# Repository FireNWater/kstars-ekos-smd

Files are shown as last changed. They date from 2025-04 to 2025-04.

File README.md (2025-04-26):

This is the Readme for my Raspberry Pi-5 Hat to control Astrophotography equipment.

This repository comes with absolutely NO Warranty, and is currently "in work".  There are several improvements I need to make to this design, the first of which is redesigning to use a larger format 5V buck converter.  The current buck converter is very small and difficult to solder using home shop air soldering techniques.

There is also a wiring bug in the 1-wire connections.  If you are going to use 1-wire, please connect directly to your Rpi or you will burn up your device and possibly the Rpi's power supply.

The UART connection works successfully.  Use ttyAMA0 and enable "UART0" on your Rpi.

I am planning on doing a complete rework of this design, hopefully before the end of 2025.  Planned improvements:

    1. Rework the Anderson Power Poles so they are used as stock instead of needing to be bent.
    2. Rework the APPs so they have a much more solid mount to the hat
    3. Extend the hat so it extends to the edge of the ethernet socket - more real estate
    4. I have found a larger 5V buck regulator that is much easier to solder using home hot air techniques
    5. Figure out why 1-wire circuit burns up the devices . . 
    6. There is a wiring bug that is fixed in the schematic, but is not fixed on the board traces.  This bug requires a bodge wire be installed on the 5V regulator to make it stable.  This is also very difficult to install.

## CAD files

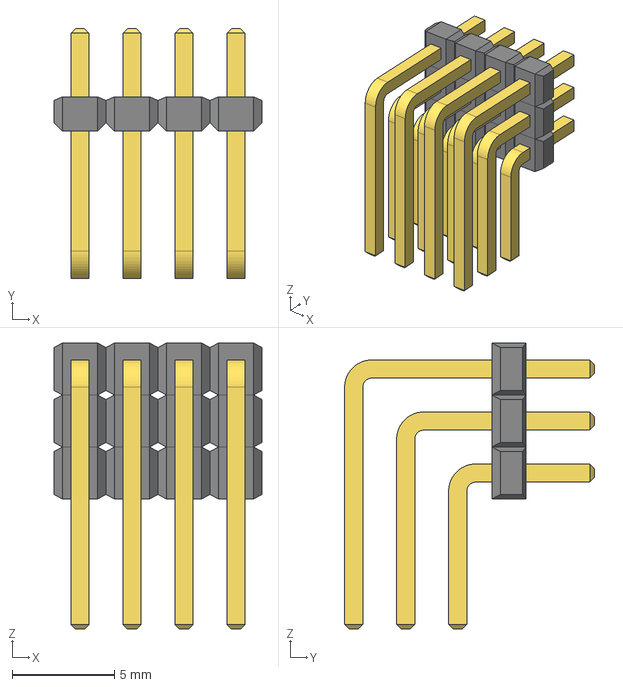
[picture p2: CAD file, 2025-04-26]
Project Library/TSW_104_08_G_T_RA/KiCADv6/TSW-104-08-T-T-RA_SAI.step
10.2 x 12.2 x 14.0 mm

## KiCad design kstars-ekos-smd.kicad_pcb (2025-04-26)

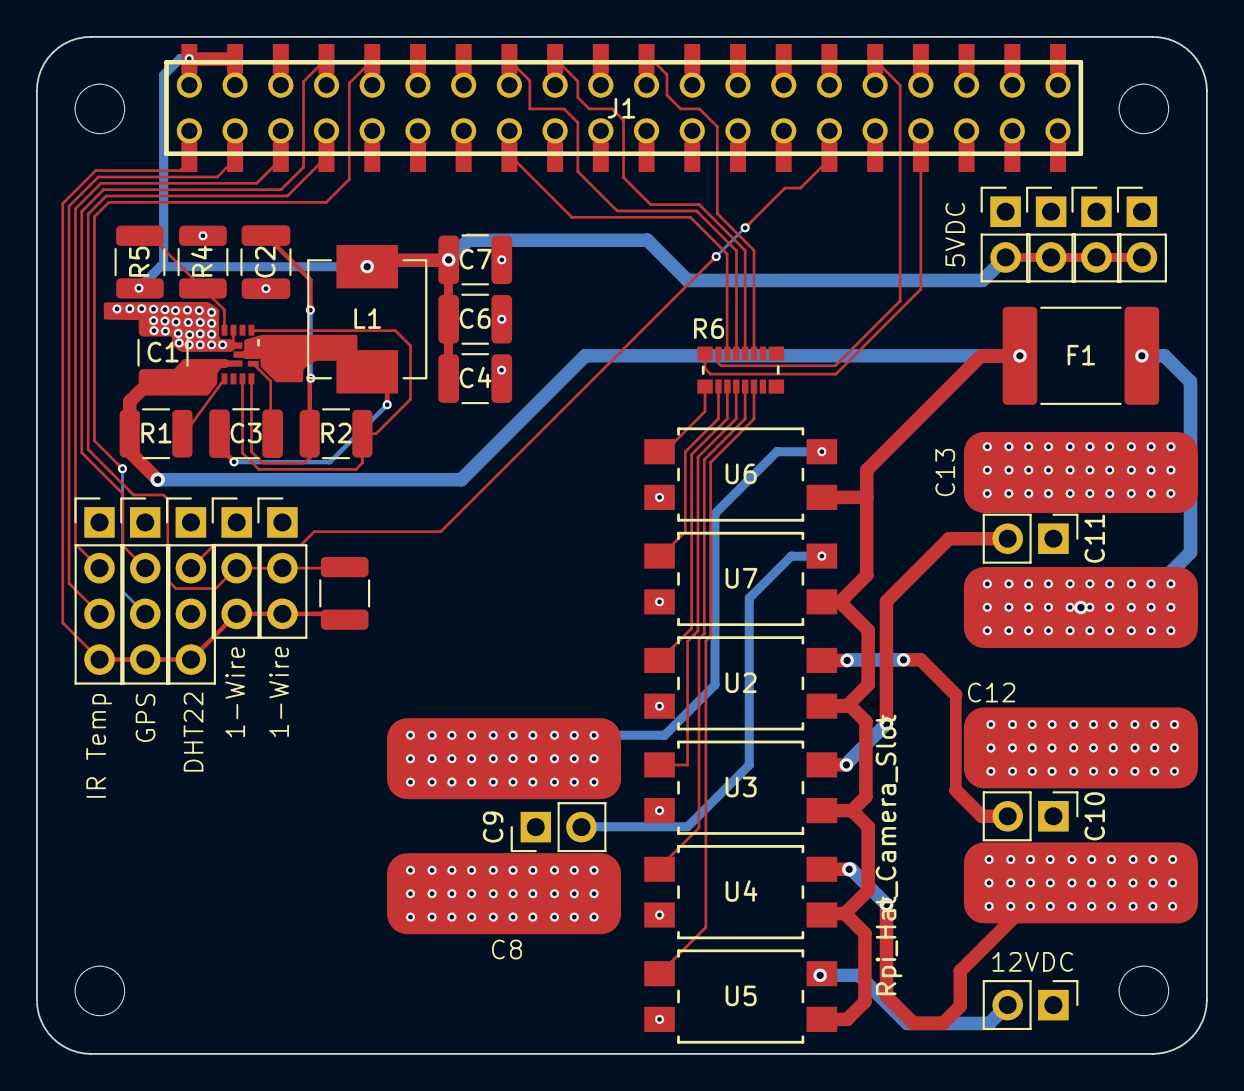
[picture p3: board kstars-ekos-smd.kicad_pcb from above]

Board: 2 copper layers, 65.0 x 56.5 mm, 38 parts (0 on the bottom side), 35 nets.

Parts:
C1, C4, C6, C7: 22uF; C_1210_3225Metric
C2: 1uF; C_1210_3225Metric
C3: 100nF; C_1210_3225Metric
C8, C12, C13: Anderson Power Pole
C9, C10, C11: PinHeader_1x02_P2.54mm_Vertical
F1: Polyfuse - 6A; Fuse_2920_7451Metric
H1, H2, H3, H4, H5: MountingHole_Pad; PinHeader_1x02_P2.54mm_Vertical
J1: Raspberry_Pi_2_3; Raspberry_Pi_40_Pin_Header_With_Lands
J2, J4: Conn_01x03; PinHeader_1x03_P2.54mm_Vertical
J3, J5, J6: Conn_01x04; PinHeader_1x04_P2.54mm_Vertical
L1: 1.0uH; L_Vishay_IHLP-2525
R1, R2: 100K; R_1210_3225Metric
R3: 47k; R_1210_3225Metric
R4: 30.1K; R_1210_3225Metric
R5: 221K; R_1210_3225Metric
R6: 560 Ohm; RES_EXB2HV
U1: AP62600SJ-7; V-QFN2030-12_A_DIO
U2, U3, U4, U5: TLP3553ATP1_F; SOIC_3553ATP1_F_TOS
U6, U7: TLP241ATP1_F; SOIC_3553ATP1_F_TOS

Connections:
+3V3: J1.1 (3V3), J2.3, J3.4, J4.3, J5.4, J6.4, R3.2
+5V: C4.2, C6.2, C7.2, H1.1, H2.1, H3.1, H4.1, J1.2 (5V), J1.4 (5V), L1.2, R5.1
+12V: C1.2, F1.1, R1.1, U1.2 (VIN), U2.3, U3.3, U4.3, U5.3, U6.3, U7.3
DC1: R6.11, U2.1
DC2: R6.12, U3.1
DC3: R6.13, U4.1
DCX: R6.14, U5.1
DC_1: J1.15 (GPIO22), R6.6
DC_2: J1.16 (GPIO23), R6.5
DC_3: J1.18 (GPIO24), R6.4
DC_X: J1.22 (GPIO25), R6.3
DH1: R6.9, U6.1
DH2: R6.10, U7.1
Dew Heater 1: J1.33 (PWM1/GPIO13), R6.8
Dew Heater 2: J1.32 (PWM0/GPIO12), R6.7
GND: C1.1, C2.1, C4.1, C6.1, C7.1, C8.2 (Ground), C9.2 (Ground), C10.2 (Ground), C11.2 (Ground), C12.2 (Ground), C13.2 (Ground), H1.2, H2.2, H3.2, H4.2, H5.2, J1.6 (GND), J1.9 (GND), J1.14 (GND), J1.20 (GND), J1.25 (GND), J1.30 (GND), J1.34 (GND), J1.39 (GND), J2.1, J3.1, J4.1, J5.1, J6.1, R4.2, U1.1 (PGND), U1.11 (GND), U2.2, U3.2, U4.2, U5.2, U6.2, U7.2
unnamed: C8.1 (Positive), U6.4
unnamed: C9.1 (Positive), U7.4
unnamed: C10.1 (Positive), U2.4
unnamed: C11.1 (Positive), U3.4
unnamed: C12.1 (Positive), U4.4
unnamed: C13.1 (Positive), F1.2
unnamed: H5.1, U5.4
unnamed: J1.7 (GCLK0/GPIO4), J2.2, J4.2, R3.1
unnamed: J1.29 (GCLK1/GPIO5), J5.2
unnamed: C3.2, U1.7 (BST)
unnamed: R1.2, U1.3 (EN)
unnamed: R4.1, R5.2, U1.12 (FB)
unnamed: R2.1, U1.5 (FSEL), U1.9 (VCC)
unnamed: C2.2, R2.2, U1.6 (PG)
unnamed: C3.1, L1.1, U1.8 (SW)
RXD: J1.10 (GPIO15/RXD), J3.3
SCL i2c: J1.5 (SCL/GPIO3), J6.2
SDA i2c: J1.3 (SDA/GPIO2), J6.3
TXD: J1.8 (GPIO14/TXD), J3.2

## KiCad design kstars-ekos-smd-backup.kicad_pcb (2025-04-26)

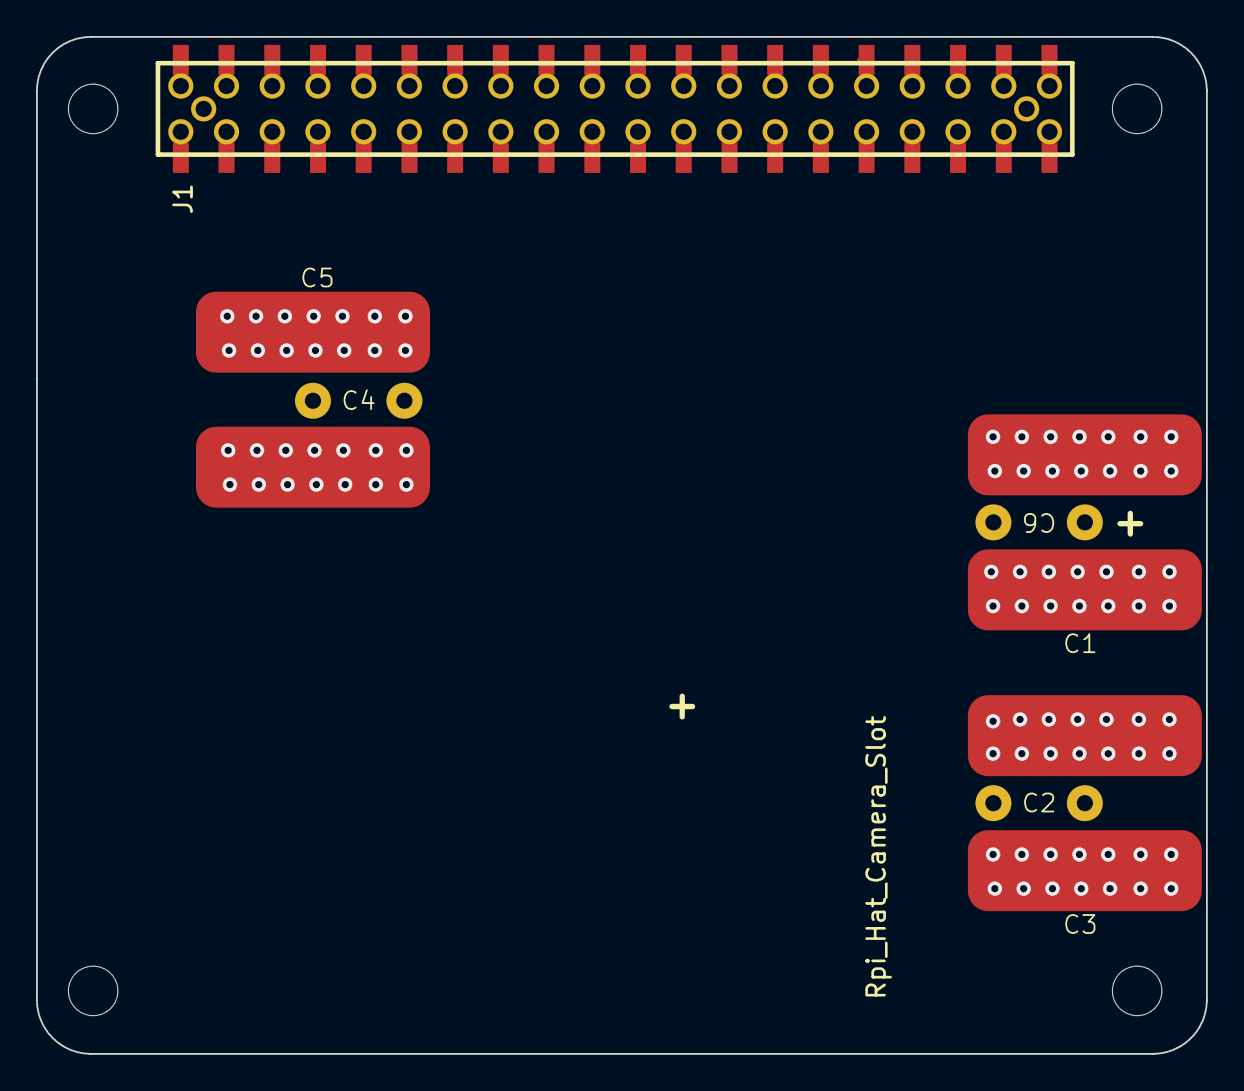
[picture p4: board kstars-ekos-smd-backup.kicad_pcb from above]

Board: 2 copper layers, 65.0 x 56.5 mm, 7 parts (0 on the bottom side), 2 nets.

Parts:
C1, C3, C5: Anderson Power Pole
C2, C4, C6: APP Through-Hole
J1: Raspberry_Pi_2_3; Samtec_HLE-120-02-XXX-DV-BE-XX-XX

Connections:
+12V: C1.1 (Positive), C2.1 (Positive), C3.1 (Positive), C4.1 (Positive), C5.1 (Positive), C6.1 (Positive)
GND: C1.2 (Ground), C2.2 (Ground), C3.2 (Ground), C6.2 (Ground), J1.39 (GND)
